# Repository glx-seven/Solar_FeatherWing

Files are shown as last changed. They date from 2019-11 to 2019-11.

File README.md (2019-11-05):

# Solar_FeatherWing
##  Description
Run your projects with free sun-power :).

The ST SPV1040 takes care of the MPPT of your solar-panel.
An integrated TI INA219 power monitor IC (at I2C address 0x48) lets you observe your battery voltage and the charge/discharge rate.

The maximum voltage of the solar-cell is 5.5V. 
Never connect batteries on your feather board (or anywhere else) and this wing at the same time.

## BOM
| Part | Value | Package | Description |
| --- | --- | --- | --- |
| C1 | 22uF | C0603K | capacitor |
| C2 | 22uF | C0603K | capacitor |
| C3 | 1nF | C0603K | capacitor |
| C4 | 1nF | C0603K | capacitor |
| C5 | 1uF | C0603K | capacitor |
| C6 | 22uF | C0603K | capacitor |
| C7 | 22uF | C0603K | capacitor |
| C8 | 22uF | C0603K | capacitor |
| C10 | 100nF | C0603K | capacitor |
| D1 | NSR0530HT1G | SOD323 | diode |
| D2 | SMBJ5339B-TP | SMB | z-diode for protection |
| IC1 | SPV1040T | TSSOP8 | Solar-charge IC |
| IC2 | INA219AIDCNR | SOT65P280X145-8N | power monitor |
| J1 | 1X2-3.5MM | 1X2-3.5MM | terminal header |
| L1 | 10uH | DR74 | inductor | Shielded Iinductor |
| MS1 | FEATHERWING | FEATHERWING | adafruit featherwing layout |
| R1 | 1k | R0603 | resistor |
| R2 | 50m | R0603 | resistor; current-limit of the charger |
| R3 | 1k | R0603 | resistor |
| R4 | 1k | R0603 | resistor |
| R5 | 1.2M | R0603 | resistor |
| R6 | 390k | R0603 | resistor |
| R7 | 100m | R1206 | resistor; shunt resistor for current-measurement |
| R8 | 4.7k | R0603 | resistor; i2c pullup |
| R9 | 4.7k | R0603 | resistor; i2c pullup |

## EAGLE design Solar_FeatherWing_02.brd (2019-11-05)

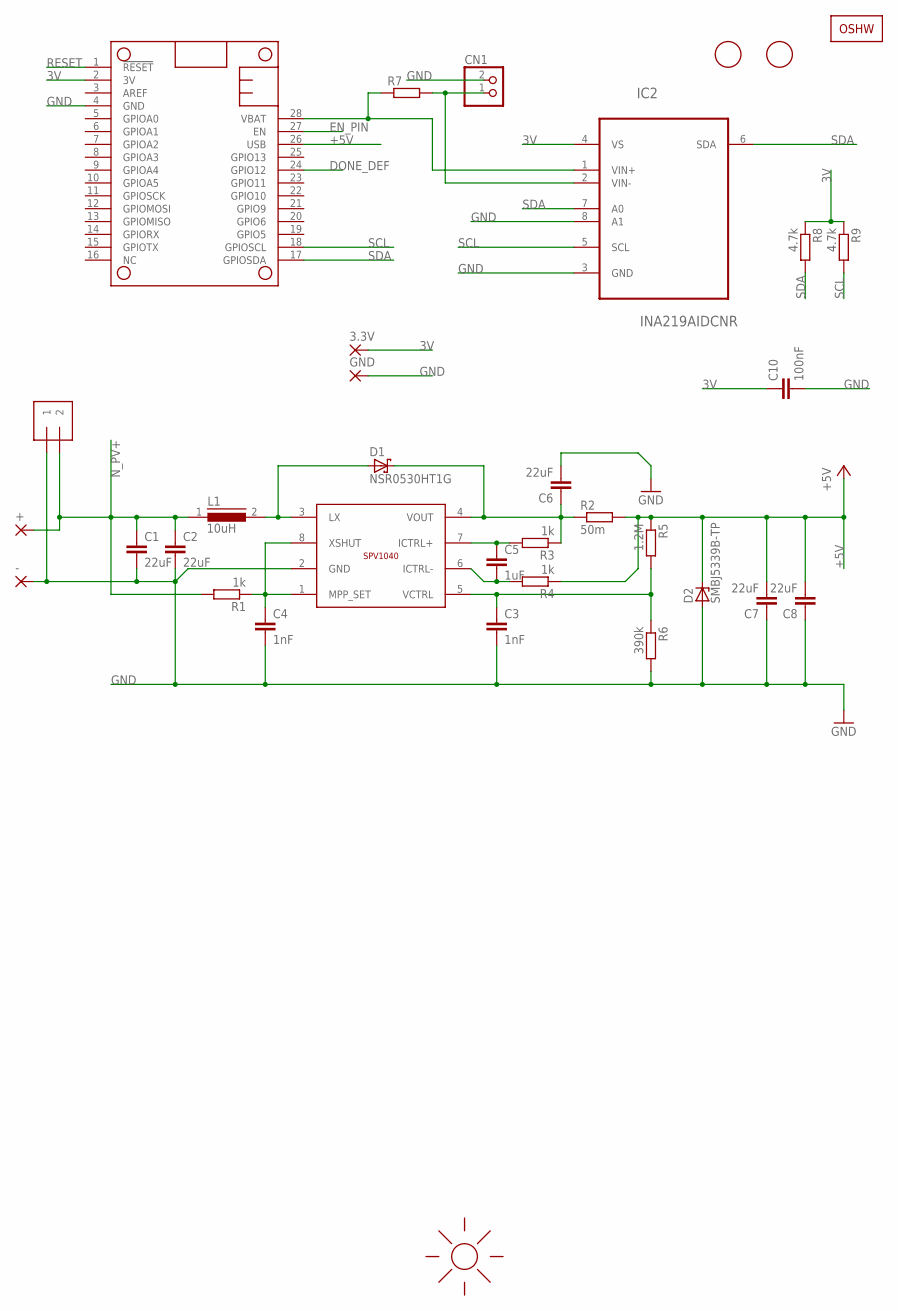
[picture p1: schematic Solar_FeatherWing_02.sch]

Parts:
3.3V: 1,6/0,9
+: 1,6/0,9
-: 1,6/0,9
C1, C2, C6, C7, C8: 22uF; C0603K
C3, C4: 1nF; C0603K
C5: 1uF; C0603K
C10: 100nF; C0603K
CN1: JST_2PIN-SMT-RA; JST-PH-2-SMT-RA
D1: NSR0530HT1G; SOD323_ST
D2: SMBJ5339B-TP; SMB
GND: 1,6/0,9
IC1: SPV1040T; TSSOP8
IC2: INA219AIDCNR; SOT65P280X145-8N
J1: 1X2-3.5MM
L1: 10uH; DR74
LOGO1: OSHW_LOGOX0100; OSHW_6X100
MS1: FEATHERWING
R1, R3, R4: 1k; R0603
R2: 50m; R0603
R5: 1.2M; R0603
R6: 390k; R0603
R7: R-EU_R1206; R1206
R8, R9: 4.7k; R0603
U$1: SUNLOGO; SUN
U$2, U$3: FIDUCIAL; FIDUCIAL_1MM

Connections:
3V: 3.3V.1, C10.1, IC2.4 (VS), MS1.2 (3V), R8.1, R9.1
+5V: C7.2, C8.2, D2.C, MS1.26 (USB), R2.2, R4.1, R5.1
DONE_DEF: MS1.24 (GPIO12)
EN_PIN: MS1.27 (EN)
GND: -.1, C1.2, C2.2, C3.2, C4.2, C6.2, C7.1, C8.1, C10.2, CN1.2 (1), D2.A, GND.1, IC1.2 (GND), IC2.3 (GND), IC2.8 (A1), J1.1, MS1.4 (GND), R6.2
LX: D1.A, IC1.3 (LX), L1.2
unnamed: C4.1, IC1.1 (MPP_SET), IC1.8 (XSHUT), R1.1
unnamed: C5.1, IC1.7 (ICTRL+), R3.2
unnamed: C5.2, IC1.6 (ICTRL-), R4.2
unnamed: C6.1, D1.C, IC1.4 (VOUT), R2.1, R3.1
unnamed: CN1.1 (2), IC2.2 (VIN-), R7.2
N_PV+: +.1, C1.1, C2.1, J1.2, L1.1, R1.2
N_VCTRL: C3.1, IC1.5 (VCTRL), R5.2, R6.1
RESET: MS1.1 (!RESET)
SCL: IC2.5 (SCL), MS1.18 (GPIOSCL), R9.2
SDA: IC2.6 (SDA), IC2.7 (A0), MS1.17 (GPIOSDA), R8.2
VBAT: IC2.1 (VIN+), MS1.28 (VBAT), R7.1

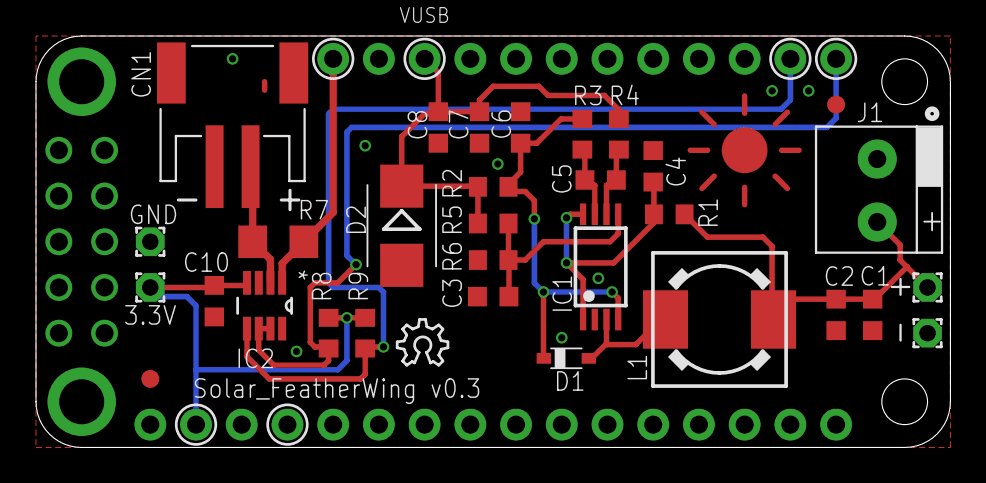
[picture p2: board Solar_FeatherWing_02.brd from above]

Board: 2 copper layers, 50.8 x 22.9 mm, 34 parts (0 on the bottom side), 14 nets.

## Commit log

2019-07-25 Initial release
    [Solar_FeatherWing_02.brd, Solar_FeatherWing_02.sch]
2019-11-04 Changed features
    Removed the timer-ic and added a INA219 to monitor power.
    [Solar_FeatherWing_02.brd, Solar_FeatherWing_02.sch]
2019-11-05 Monitor battery current and voltage
    [Solar_FeatherWing_02.brd, Solar_FeatherWing_02.sch]
